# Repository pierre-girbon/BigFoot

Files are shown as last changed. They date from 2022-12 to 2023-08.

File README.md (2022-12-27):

Big Foot
=========
Foot switch midi controller

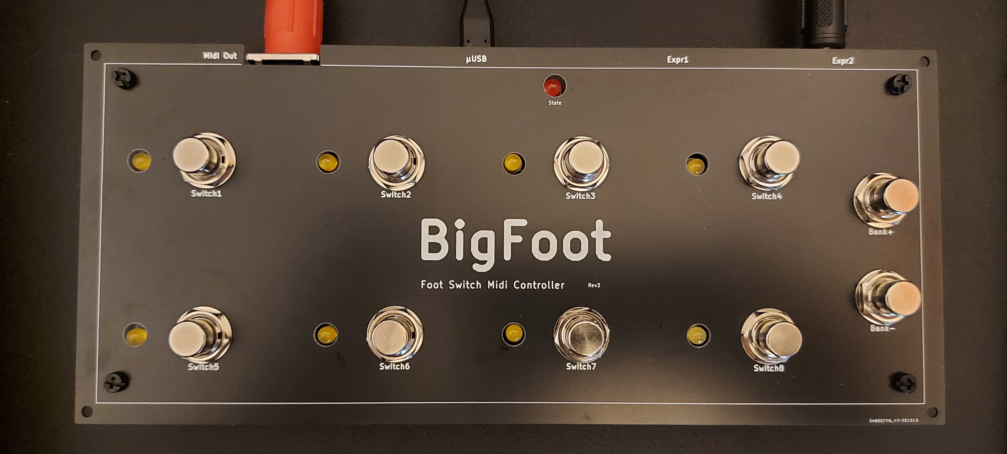
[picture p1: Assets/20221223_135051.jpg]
Top

Rear

Features
--------

    1. 8 assignable footswitches
    2. Bank selection
    3. 2 expression pedals connectors with TRS/RTS switch
    4. USB Midi input and output
    5. Midi DIN output
    6. (TODO) LED feedback

Presets Setup
-------------
Preset must be defined into a '.h' file in the Firmware/include folder, then included into Firmware/src/main.cpp file (see RolandMC707.h file as example) and compiled.

See [Control Surface](https://github.com/tttapa/Control-Surface) library for possible presets.

Building
--------

Folder structure:

- PCB: KiCAD schematics and PCB
    - Gerber: gerger files to order PCB production
    - [Mouser part list](https://www.mouser.fr/ProjectManager/ProjectDetail.aspx?AccessID=45c124cc8a)
- Enclosure: KiCAD files for the top panel
- Firware: source code

Compiling source code requires [platformio](https://docs.platformio.org/en/latest/)

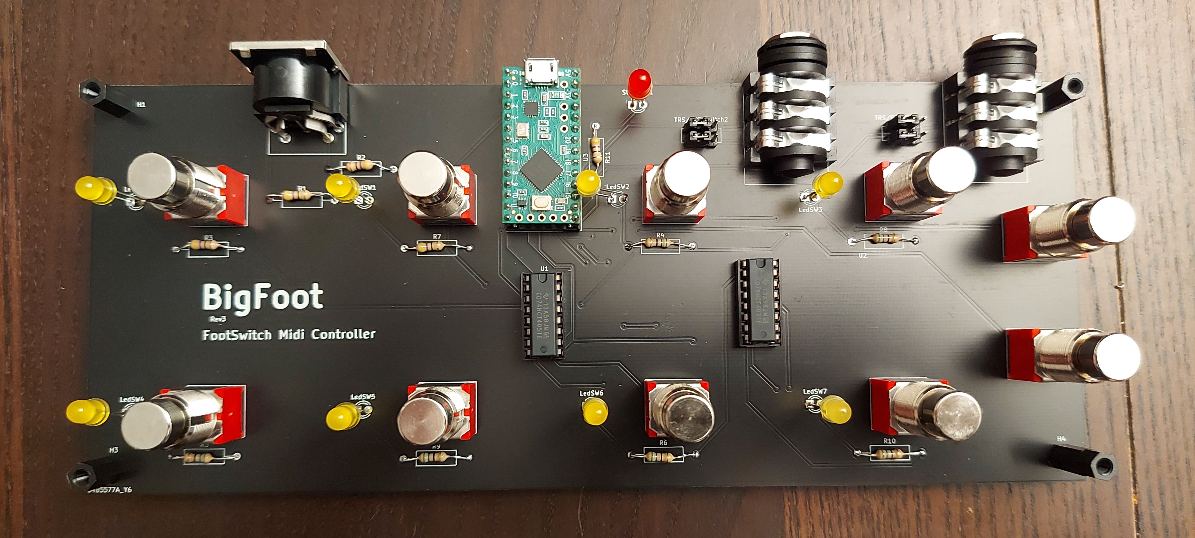
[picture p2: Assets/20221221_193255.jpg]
Inside


Licence
-------
[CC BY-NC 4.0](https://creativecommons.org/licenses/by-nc/4.0/)

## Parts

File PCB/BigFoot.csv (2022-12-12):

Source: | /home/pierreg/Documents/LifeStyle/Electronics/Projects/BigFoot/PCB/BigFoot.kicad_sch
Date: | lun. 12 déc. 2022 15:57:01
Tool: | Eeschema (6.0.9)
Generator: | /usr/share/kicad/plugins/bom_csv_grouped_by_value.py
Component Count: | 42
Individual Components:
Item | Qty | Reference(s) | Value | LibPart | Footprint | Datasheet
 |  | BankSwitch+1 | FS5700SPMT2B2M1QEH | Switch:SW_SPDT | Switch:Switch_Foot_SPDT_Momentary_Eswitch_FS5700SPMT2B2M1QEH | https://sten-eswitch-13110800-production.s3.amazonaws.com/system/asset/product_line/data_sheet/226/FS5700.pdf
 |  | BankSwith-1 | FS5700SPMT2B2M1QEH | Switch:SW_SPDT | Switch:Switch_Foot_SPDT_Momentary_Eswitch_FS5700SPMT2B2M1QEH | https://sten-eswitch-13110800-production.s3.amazonaws.com/system/asset/product_line/data_sheet/226/FS5700.pdf
 |  | ExprPedalJack1 | ACJS-IH | Connector:AudioJack3 | Connectors:Jack_6.35_Horizontal_Amphenol_ACJS-IH | https://www.amphenolaudio.com/products/14-2/m-series/
 |  | ExprPedalJack2 | ACJS-IH | Connector:AudioJack3 | Connectors:Jack_6.35_Horizontal_Amphenol_ACJS-IH | https://www.amphenolaudio.com/products/14-2/m-series/
 |  | FootSwitch0 | FS5700SPMT2B2M1QEH | Switch:SW_SPDT | Switch:Switch_Foot_SPDT_Momentary_Eswitch_FS5700SPMT2B2M1QEH | https://sten-eswitch-13110800-production.s3.amazonaws.com/system/asset/product_line/data_sheet/226/FS5700.pdf
 |  | FootSwitch1 | FS5700SPMT2B2M1QEH | Switch:SW_SPDT | Switch:Switch_Foot_SPDT_Momentary_Eswitch_FS5700SPMT2B2M1QEH | https://sten-eswitch-13110800-production.s3.amazonaws.com/system/asset/product_line/data_sheet/226/FS5700.pdf
 |  | FootSwitch2 | FS5700SPMT2B2M1QEH | Switch:SW_SPDT | Switch:Switch_Foot_SPDT_Momentary_Eswitch_FS5700SPMT2B2M1QEH | https://sten-eswitch-13110800-production.s3.amazonaws.com/system/asset/product_line/data_sheet/226/FS5700.pdf
 |  | FootSwitch3 | FS5700SPMT2B2M1QEH | Switch:SW_SPDT | Switch:Switch_Foot_SPDT_Momentary_Eswitch_FS5700SPMT2B2M1QEH | https://sten-eswitch-13110800-production.s3.amazonaws.com/system/asset/product_line/data_sheet/226/FS5700.pdf
 |  | FootSwitch4 | FS5700SPMT2B2M1QEH | Switch:SW_SPDT | Switch:Switch_Foot_SPDT_Momentary_Eswitch_FS5700SPMT2B2M1QEH | https://sten-eswitch-13110800-production.s3.amazonaws.com/system/asset/product_line/data_sheet/226/FS5700.pdf
 |  | FootSwitch5 | FS5700SPMT2B2M1QEH | Switch:SW_SPDT | Switch:Switch_Foot_SPDT_Momentary_Eswitch_FS5700SPMT2B2M1QEH | https://sten-eswitch-13110800-production.s3.amazonaws.com/system/asset/product_line/data_sheet/226/FS5700.pdf
 |  | FootSwitch6 | FS5700SPMT2B2M1QEH | Switch:SW_SPDT | Switch:Switch_Foot_SPDT_Momentary_Eswitch_FS5700SPMT2B2M1QEH | https://sten-eswitch-13110800-production.s3.amazonaws.com/system/asset/product_line/data_sheet/226/FS5700.pdf
 |  | FootSwitch7 | FS5700SPMT2B2M1QEH | Switch:SW_SPDT | Switch:Switch_Foot_SPDT_Momentary_Eswitch_FS5700SPMT2B2M1QEH | https://sten-eswitch-13110800-production.s3.amazonaws.com/system/asset/product_line/data_sheet/226/FS5700.pdf
 |  | H1 | MountingHole | Mechanical:MountingHole | MountingHole:MountingHole_3.2mm_M3 | ~
 |  | H2 | MountingHole | Mechanical:MountingHole | MountingHole:MountingHole_3.2mm_M3 | ~
 |  | H3 | MountingHole | Mechanical:MountingHole | MountingHole:MountingHole_3.2mm_M3 | ~
 |  | H4 | MountingHole | Mechanical:MountingHole | MountingHole:MountingHole_3.2mm_M3 | ~
 |  | LedSW0 | TLHR4400-AS12Z | Device:LED | LED_THT:LED_D3.0mm | https://www.mouser.fr/datasheet/2/427/tlhg440-1766941.pdf
 |  | LedSW1 | TLHR4400-AS12Z | Device:LED | LED_THT:LED_D3.0mm | https://www.mouser.fr/datasheet/2/427/tlhg440-1766941.pdf
 |  | LedSW2 | TLHR4400-AS12Z | Device:LED | LED_THT:LED_D3.0mm | https://www.mouser.fr/datasheet/2/427/tlhg440-1766941.pdf
 |  | LedSW3 | TLHR4400-AS12Z | Device:LED | LED_THT:LED_D3.0mm | https://www.mouser.fr/datasheet/2/427/tlhg440-1766941.pdf
 |  | LedSW4 | TLHR4400-AS12Z | Device:LED | LED_THT:LED_D3.0mm | https://www.mouser.fr/datasheet/2/427/tlhg440-1766941.pdf
 |  | LedSW5 | TLHR4400-AS12Z | Device:LED | LED_THT:LED_D3.0mm | https://www.mouser.fr/datasheet/2/427/tlhg440-1766941.pdf
 |  | LedSW6 | TLHR4400-AS12Z | Device:LED | LED_THT:LED_D3.0mm | https://www.mouser.fr/datasheet/2/427/tlhg440-1766941.pdf
 |  | LedSW7 | TLHR4400-AS12Z | Device:LED | LED_THT:LED_D3.0mm | https://www.mouser.fr/datasheet/2/427/tlhg440-1766941.pdf
 |  | MidiOut1 | KCDX-5S-S2 | Connector:DIN-5_180degree | Connectors:Circular_DIN_5P_KCDX-5S-S2 | https://www.mouser.fr/datasheet/2/222/KCDX-334811.pdf
 |  | R1 | 47 | Device:R | Resistor_THT:R_Axial_DIN0309_L9.0mm_D3.2mm_P15.24mm_Horizontal | ~
 |  | R2 | 47 | Device:R | Resistor_THT:R_Axial_DIN0309_L9.0mm_D3.2mm_P15.24mm_Horizontal | ~
 |  | R3 | 47 | Device:R | Resistor_THT:R_Axial_DIN0309_L9.0mm_D3.2mm_P15.24mm_Horizontal | ~
 |  | R4 | 47 | Device:R | Resistor_THT:R_Axial_DIN0309_L9.0mm_D3.2mm_P15.24mm_Horizontal | ~
 |  | R5 | 47 | Device:R | Resistor_THT:R_Axial_DIN0309_L9.0mm_D3.2mm_P15.24mm_Horizontal | ~
 |  | R6 | 47 | Device:R | Resistor_THT:R_Axial_DIN0309_L9.0mm_D3.2mm_P15.24mm_Horizontal | ~
 |  | R7 | 47 | Device:R | Resistor_THT:R_Axial_DIN0309_L9.0mm_D3.2mm_P15.24mm_Horizontal | ~
 |  | R8 | 47 | Device:R | Resistor_THT:R_Axial_DIN0309_L9.0mm_D3.2mm_P15.24mm_Horizontal | ~
 |  | R9 | 47 | Device:R | Resistor_THT:R_Axial_DIN0309_L9.0mm_D3.2mm_P15.24mm_Horizontal | ~
 |  | R10 | 47 | Device:R | Resistor_THT:R_Axial_DIN0309_L9.0mm_D3.2mm_P15.24mm_Horizontal | ~
 |  | R11 | 47 | Device:R | Resistor_THT:R_Axial_DIN0309_L9.0mm_D3.2mm_P15.24mm_Horizontal | ~
 |  | StateLED1 | TLHR4400-AS12Z | Device:LED | LED_THT:LED_D3.0mm | https://www.mouser.fr/datasheet/2/427/tlhg440-1766941.pdf
 |  | TRS/RTS_Switch1 | LSSA22L-V | Switch:SW_Push_DPDT | Switch:Switch_slide_2PDT_LSSA22L-V | ~
 |  | TRS/RTS_Switch2 | LSSA22L-V | Switch:SW_Push_DPDT | Switch:Switch_slide_2PDT_LSSA22L-V | ~
 |  | U1 | 74HCT4051 | 74xx:74HC4051 | Package_DIP:DIP-16_W7.62mm | http://www.ti.com/lit/ds/symlink/cd74hc4051.pdf
 |  | U2 | 74HCT4051 | 74xx:74HC4051 | Package_DIP:DIP-16_W7.62mm | http://www.ti.com/lit/ds/symlink/cd74hc4051.pdf
 |  | U3 | Teensy-LC | teensy:Teensy-LC | teensy:Teensy_LC
Collated Components:
Item | Qty | Reference(s) | Value | LibPart | Footprint | Datasheet
1 | 10 | BankSwitch+1, BankSwith-1, FootSwitch0, FootSwitch1, FootSwitch2, FootSwitch3, FootSwitch4, FootSwitch5, FootSwitch6, FootSwitch7 | FS5700SPMT2B2M1QEH | Switch:SW_SPDT | Switch:Switch_Foot_SPDT_Momentary_Eswitch_FS5700SPMT2B2M1QEH | https://sten-eswitch-13110800-production.s3.amazonaws.com/system/asset/product_line/data_sheet/226/FS5700.pdf
2 | 2 | ExprPedalJack1, ExprPedalJack2 | ACJS-IH | Connector:AudioJack3 | Connectors:Jack_6.35_Horizontal_Amphenol_ACJS-IH | https://www.amphenolaudio.com/products/14-2/m-series/
3 | 4 | H1, H2, H3, H4 | MountingHole | Mechanical:MountingHole | MountingHole:MountingHole_3.2mm_M3 | ~
4 | 9 | LedSW0, LedSW1, LedSW2, LedSW3, LedSW4, LedSW5, LedSW6, LedSW7, StateLED1 | TLHR4400-AS12Z | Device:LED | LED_THT:LED_D3.0mm | https://www.mouser.fr/datasheet/2/427/tlhg440-1766941.pdf
5 | 1 | MidiOut1 | KCDX-5S-S2 | Connector:DIN-5_180degree | Connectors:Circular_DIN_5P_KCDX-5S-S2 | https://www.mouser.fr/datasheet/2/222/KCDX-334811.pdf
6 | 11 | R1, R2, R3, R4, R5, R6, R7, R8, R9, R10, R11 | 47 | Device:R | Resistor_THT:R_Axial_DIN0309_L9.0mm_D3.2mm_P15.24mm_Horizontal | ~
7 | 2 | TRS/RTS_Switch1, TRS/RTS_Switch2 | LSSA22L-V | Switch:SW_Push_DPDT | Switch:Switch_slide_2PDT_LSSA22L-V | ~
8 | 2 | U1, U2 | 74HCT4051 | 74xx:74HC4051 | Package_DIP:DIP-16_W7.62mm | http://www.ti.com/lit/ds/symlink/cd74hc4051.pdf
9 | 1 | U3 | Teensy-LC | teensy:Teensy-LC | teensy:Teensy_LC

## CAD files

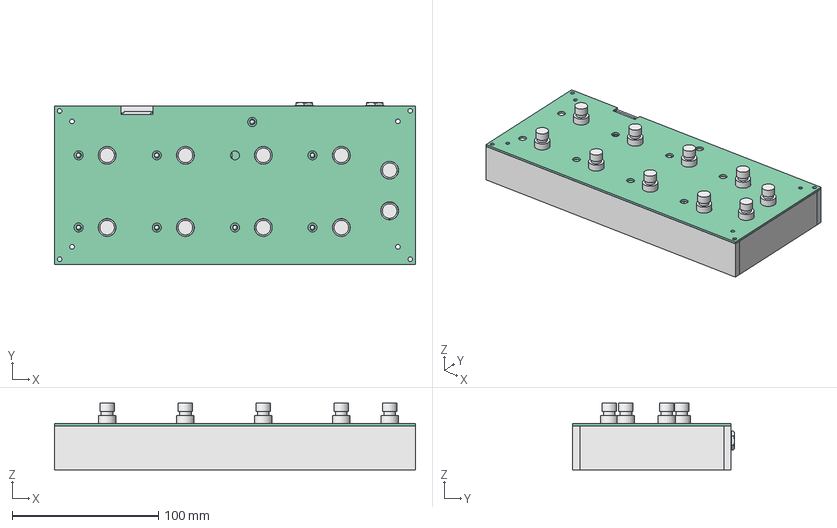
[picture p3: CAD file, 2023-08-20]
Enclosure/BigFoot-Enclosure.FCStd
247.0 x 110.6 x 45.5 mm
Pcb_4896
Pcb_fa5
R3_R_Axial_DIN0309_L90mm_D32mm_P1524mm_Horizontal_8798602e830f x 11
LedSW4_LED_D3.0mm_6cc97a295512 x 9
FootSwitch7_Body_7403e81f2288 x 10
ACJS-IH_Shrinkwrap_1 x 2
ACJS-IH_Shrinkwrap_002 x 2
ACJS-IH_Shrinkwrap_003 x 2
ACJS-IH_Shrinkwrap_004 x 2
ACJS-IH_Shrinkwrap_005 x 2
ACJS-IH_Shrinkwrap_006 x 2
ACJS-IH_Shrinkwrap_007 x 2
ACJS-IH_Shrinkwrap_008 x 2
ACJS-IH_Shrinkwrap_009 x 2
ACJS-IH_Shrinkwrap_010 x 2
ACJS-IH_Shrinkwrap_011 x 2
ACJS-IH_Shrinkwrap_012 x 2
ACJS-IH_Shrinkwrap_013 x 2
ACJS-IH_Shrinkwrap_014 x 2
ACJS-IH_Shrinkwrap_015 x 2
ACJS-IH_Shrinkwrap_016 x 2
ACJS-IH_Shrinkwrap_017 x 2
ACJS-IH_Shrinkwrap_018 x 2
U1_DIP-16_W7.62mm_09a87ed791be x 2
MidiOut1_KCDX-xS-N2_4d28036a2862
board
Group#12 (1)
Group#12 (1)001
Group#12 (1)002
Group#12 (1)003
Group#12 (1)004
micro_usb_plastic (1)
micro_usb_shell (1)
lead
lead001
lead002
lead003
lead004
lead005
lead006
lead007
lead008
lead009
lead010
lead011
lead012
lead013
lead014
lead015
diode_0402 v1
diode_0402 v002
diode_0402 v003
cap0603_03 v3
cap0603_03 v004
cap0603_03 v005
diode_0402 v005
diode_0402 v006
diode_0402 v007
diode_0402 v009
diode_0402 v010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

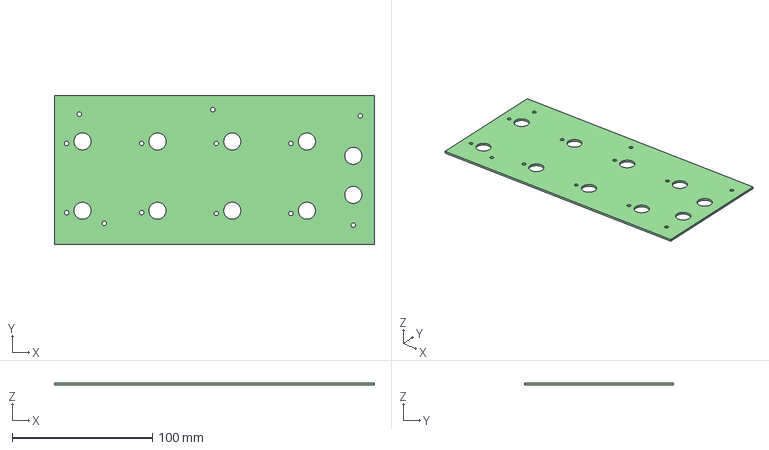
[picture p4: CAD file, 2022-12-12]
Enclosure/BigFoot-Enclosure/BigFoot-Enclosure.step
228.4 x 106.5 x 1.60 mm

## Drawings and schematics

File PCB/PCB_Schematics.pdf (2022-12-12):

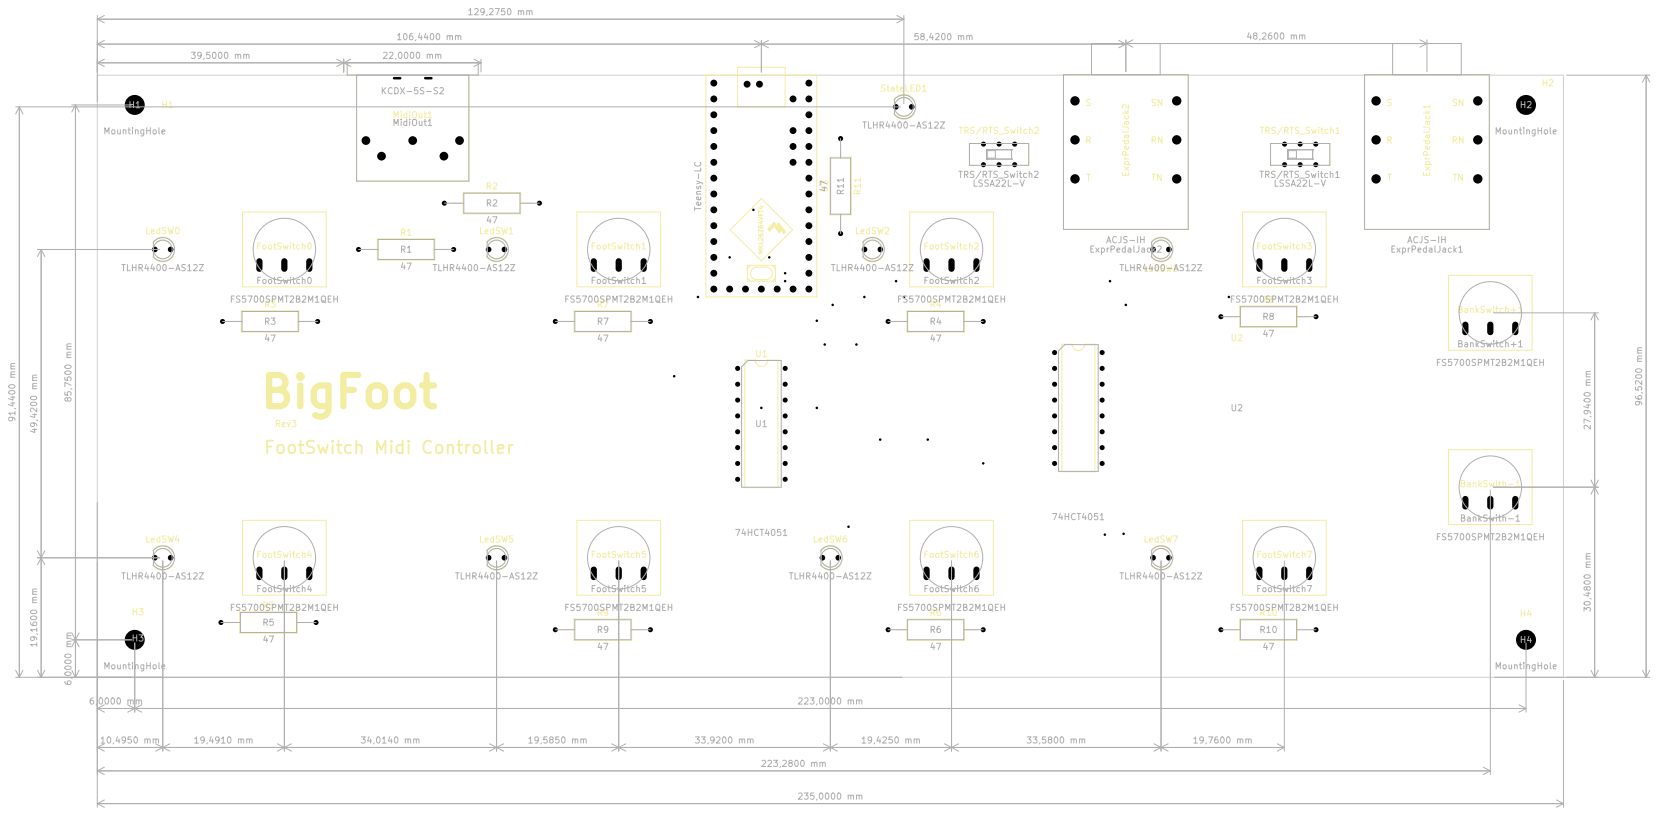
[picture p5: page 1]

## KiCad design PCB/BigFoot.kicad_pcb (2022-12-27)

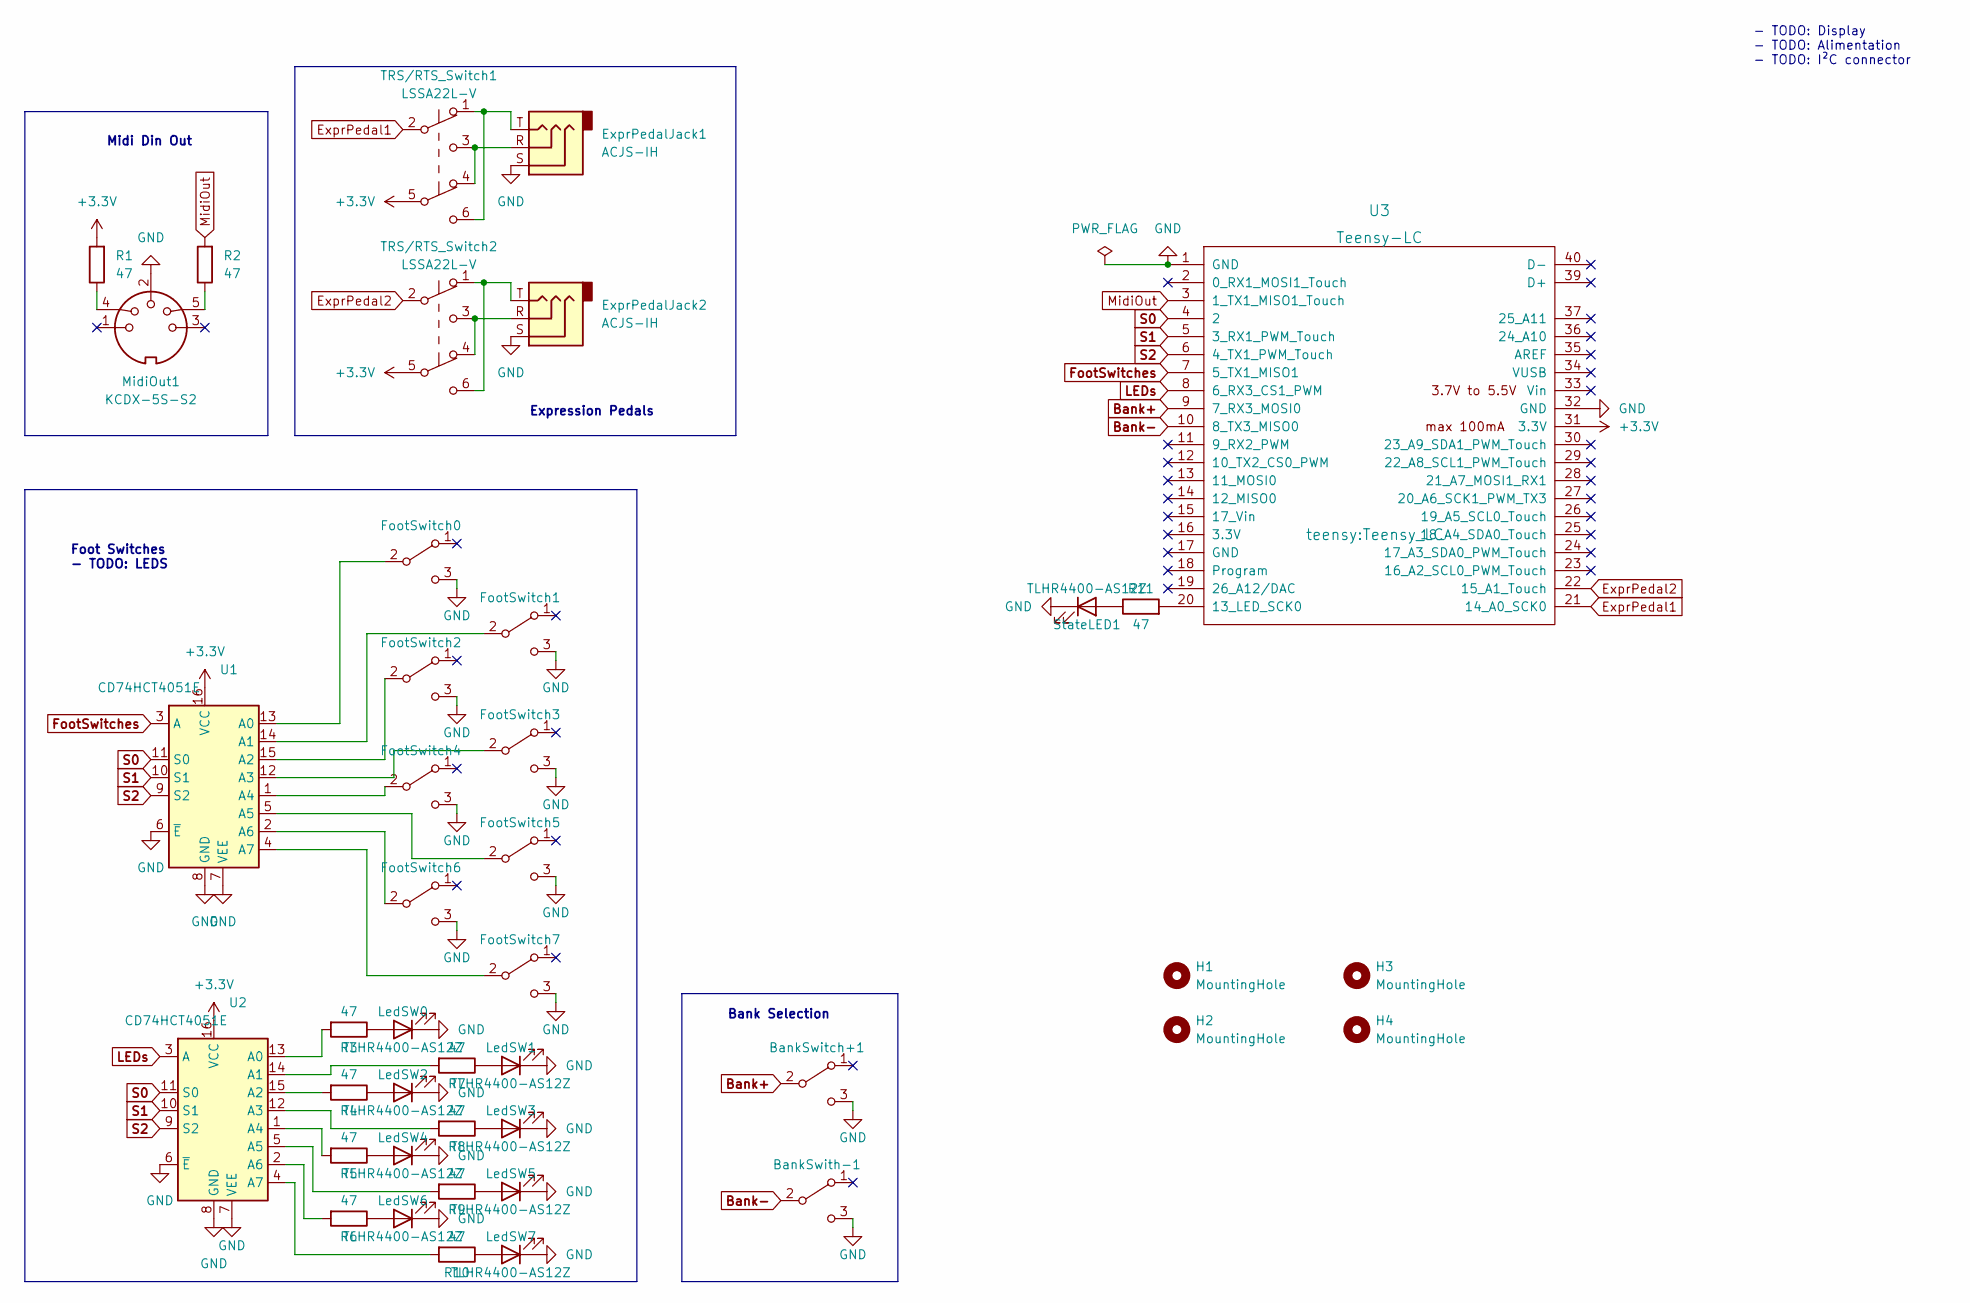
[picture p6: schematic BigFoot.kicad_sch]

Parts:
BankSwitch+1: FS5700SPMT2B2M1QEH; Switch_Foot_SPDT_Momentary_Eswitch_FS5700SPMT2B2M1QEH
BankSwith-1: FS5700SPMT2B2M1QEH; Switch_Foot_SPDT_Momentary_Eswitch_FS5700SPMT2B2M1QEH
ExprPedalJack1, ExprPedalJack2: ACJS-IH; Jack_6.35_Horizontal_Amphenol_ACJS-IH
FootSwitch0, FootSwitch1, FootSwitch2, FootSwitch3, FootSwitch4, FootSwitch5, FootSwitch6, FootSwitch7: FS5700SPMT2B2M1QEH; Switch_Foot_SPDT_Momentary_Eswitch_FS5700SPMT2B2M1QEH
H1, H2, H3, H4: MountingHole; MountingHole_3.2mm_M3
LedSW0, LedSW1, LedSW2, LedSW3, LedSW4, LedSW5, LedSW6, LedSW7: TLHR4400-AS12Z; LED_D3.0mm
MidiOut1: KCDX-5S-S2; Circular_DIN_5P_KCDX-5S-S2
R1, R2, R3, R4, R5, R6, R7, R8, R9, R10, R11: 47; R_Axial_DIN0309_L9.0mm_D3.2mm_P15.24mm_Horizontal
StateLED1: TLHR4400-AS12Z; LED_D3.0mm
TRS/RTS_Switch1, TRS/RTS_Switch2: LSSA22L-V; Switch_slide_2PDT_LSSA22L-V
U1, U2: CD74HCT4051E; DIP-16_W7.62mm
U3: Teensy-LC; Teensy_LC

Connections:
+3.3V: R1.2, TRS/RTS_Switch1.5 (B), TRS/RTS_Switch2.5 (B), U1.16 (VCC), U2.16 (VCC), U3.31 (3.3V)
Bank+: BankSwitch+1.2 (B), U3.9 (7_RX3_MOSI0)
Bank-: BankSwith-1.2 (B), U3.10 (8_TX3_MISO0)
ExprPedal1: TRS/RTS_Switch1.2 (B), U3.21 (14_A0_SCK0)
ExprPedal2: TRS/RTS_Switch2.2 (B), U3.22 (15_A1_Touch)
FootSwitches: U1.3 (A), U3.7 (5_TX1_MISO1)
GND: BankSwitch+1.3 (C), BankSwith-1.3 (C), ExprPedalJack1.S, ExprPedalJack2.S, FootSwitch0.3 (C), FootSwitch1.3 (C), FootSwitch2.3 (C), FootSwitch3.3 (C), FootSwitch4.3 (C), FootSwitch5.3 (C), FootSwitch6.3 (C), FootSwitch7.3 (C), LedSW0.1 (K), LedSW1.1 (K), LedSW2.1 (K), LedSW3.1 (K), LedSW4.1 (K), LedSW5.1 (K), LedSW6.1 (K), LedSW7.1 (K), MidiOut1.2, StateLED1.1 (K), U1.6 (~E), U1.7 (VEE), U1.8 (GND), U2.6 (~E), U2.7 (VEE), U2.8 (GND), U3.1 (GND), U3.32 (GND)
LEDs: U2.3 (A), U3.8 (6_RX3_CS1_PWM)
MidiOut: R2.2, U3.3 (1_TX1_MISO1_Touch)
unnamed: ExprPedalJack1.R, TRS/RTS_Switch1.3 (C), TRS/RTS_Switch1.4 (A)
unnamed: ExprPedalJack1.T, TRS/RTS_Switch1.1 (A), TRS/RTS_Switch1.6 (C)
unnamed: ExprPedalJack2.R, TRS/RTS_Switch2.3 (C), TRS/RTS_Switch2.4 (A)
unnamed: ExprPedalJack2.T, TRS/RTS_Switch2.1 (A), TRS/RTS_Switch2.6 (C)
unnamed: FootSwitch0.2 (B), U1.13 (A0)
unnamed: FootSwitch1.2 (B), U1.14 (A1)
unnamed: FootSwitch2.2 (B), U1.15 (A2)
unnamed: FootSwitch3.2 (B), U1.12 (A3)
unnamed: FootSwitch4.2 (B), U1.1 (A4)
unnamed: FootSwitch5.2 (B), U1.5 (A5)
unnamed: FootSwitch6.2 (B), U1.2 (A6)
unnamed: FootSwitch7.2 (B), U1.4 (A7)
unnamed: LedSW0.2 (A), R3.1
unnamed: LedSW1.2 (A), R7.1
unnamed: LedSW2.2 (A), R4.1
unnamed: LedSW3.2 (A), R8.1
unnamed: LedSW4.2 (A), R5.1
unnamed: LedSW5.2 (A), R9.1
unnamed: LedSW6.2 (A), R6.1
unnamed: LedSW7.2 (A), R10.1
unnamed: MidiOut1.4, R1.1
unnamed: MidiOut1.5, R2.1
unnamed: R3.2, U2.13 (A0)
unnamed: R4.2, U2.15 (A2)
unnamed: R5.2, U2.1 (A4)
unnamed: R6.2, U2.2 (A6)
unnamed: R7.2, U2.14 (A1)
unnamed: R8.2, U2.12 (A3)
unnamed: R9.2, U2.5 (A5)
unnamed: R10.2, U2.4 (A7)
unnamed: R11.2, U3.20 (13_LED_SCK0)
unnamed: R11.1, StateLED1.2 (A)
S0: U1.11 (S0), U2.11 (S0), U3.4 (2)
S1: U1.10 (S1), U2.10 (S1), U3.5 (3_RX1_PWM_Touch)
S2: U1.9 (S2), U2.9 (S2), U3.6 (4_TX1_PWM_Touch)

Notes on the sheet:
Foot Switches - TODO: LEDS
Expression Pedals
- TODO: Display - TODO: Alimentation - TODO: I²C connector
Bank Selection
Midi Din Out

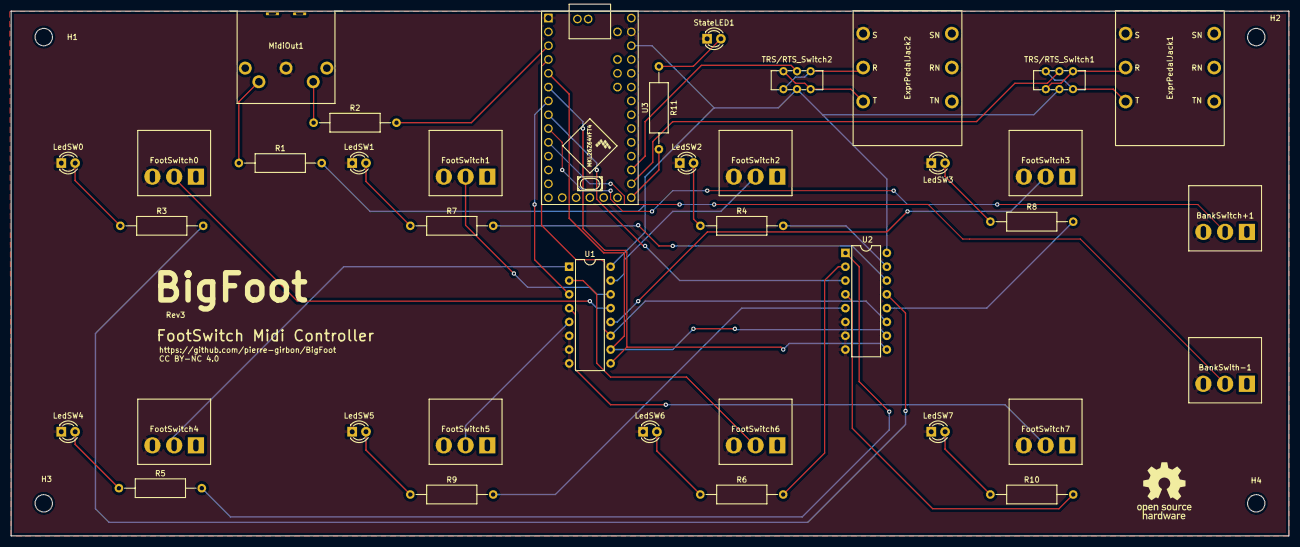
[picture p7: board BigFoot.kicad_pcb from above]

Board: 2 copper layers, 235.0 x 96.5 mm, 42 parts (0 on the bottom side), 44 nets.

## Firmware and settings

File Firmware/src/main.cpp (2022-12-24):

#include <Arduino.h>
#include <Control_Surface.h>

#include "RolandMC707.h"

#define LEDBUILTIN	13

// Midi Interfaces
USBMIDI_Interface usbMidi;
HardwareSerialMIDI_Interface serialMidi {Serial1, MIDI_BAUD};

BidirectionalMIDI_PipeFactory<2> pipes;

void setup() {
	// Led Builtin setup
	pinMode(LEDBUILTIN, OUTPUT);
	digitalWrite(LEDBUILTIN, HIGH);
	delay(800);
	digitalWrite(LEDBUILTIN, LOW);

	// Serial monitor Setup
	Serial.begin(9600);
	Serial.print("Welcome to BigFoot");

	// Control Surface setup
	Control_Surface | pipes | usbMidi;
	Control_Surface | pipes | serialMidi;
	Control_Surface.begin();
}

void loop() {
	Control_Surface.loop();
}

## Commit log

2022-12-12 Final PCB Version
    [BigFoot-B_Cu.gbr, BigFoot-B_Mask.gbr, BigFoot-B_Paste.gbr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]
2022-12-12 Panel PCB
    [BigFoot-Enclosure-B_Cu.gbr, BigFoot-Enclosure-B_Fab.gbr, BigFoot-Enclosure-B_Mask.gbr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]
2022-12-21 Minor changes on PCB
    [BigFoot.kicad_pcb]
2022-12-27 Pre Release version
    [BigFoot-Enclosure.kicad_pcb, BigFoot.kicad_pcb]
2022-12-27 Version 3.0
    [BigFoot-B_Cu.gbr, BigFoot-B_Mask.gbr, BigFoot-B_Paste.gbr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]
2023-01-02 Initial KorgD1 setup (not working)
    [main.cpp]
2023-08-20 Enclosure modif
    [BigFoot-Enclosure.FCStd, BigFoot-Enclosure.kicad_pcb]
2023-08-20 plateformio.ini modif on Control Surface version
